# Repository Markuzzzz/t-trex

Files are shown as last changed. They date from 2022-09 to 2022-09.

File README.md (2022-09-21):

# t-trex
Python based quadruped robot powered by Raspberry Pi Zero 2 W



# nifty-inspirations
Nifty Projects - because simple solutions are hard to find!

## Description

t-trex for Raspberry Pi is based on the [Sunfounder Remote Control Crawling Robot](https://www.elektormagazine.com/news/review-sunfounder-remote-control-crawling-quadruped-robot-v2-0) by panerqiang@sunfounder.com, which was the main starting point of the Python code for this project. Especially the calculations related to kinematics of the legs was very helpful. [Regis Hsu](https://www.instructables.com/DIY-Spider-RobotQuad-robot-Quadruped/) on his turn created an amazing 3D printed Quadruped frame which was also based on the Sunfounder project. t-trex is fundamentally built on the work of these two projects to jumpstart and extend with new features. The code written in C was ported to Python and fully refactored, because this programming language is focussed more on the ease of development. So easy to step in for beginners. And when Python is not fast enough (like compiled C code is), it can be combined with the low level C-language. Python is also very popular in the AI community and embedded solutions, resulting in massive amount of libraries to your disposal. Last but not least, Python is also very well supported by the Raspberry Pi ecosystem. 

More to come soon, as I will upload resources to github!

## Features
- Fully Python 3 compatible

- Remote SSH over Wifi support

- PS4 Controller support ([python-evdev](https://python-evdev.readthedocs.io/en/latest/))
    * Crawling Gait Control
    * Speed up/down movements
    * Graceful Quit Program Hard Shutdown (mode 1 soft shutdown)
    * Rumble support
    * System report (mode 1 default stance)

- Different Crwaling Gaits implemented
    * Forward 
    * Backward
    * Left
    * Right
    * Stand (mode 1 head up)
    * Sit (mode 1 head down)
    * Head up/down

- PiJuice Zero Hat
    * Monitoring by PiJuice Zero for save shutdown on low battery voltage
    * custom led usage for simple messages
    * custom switch support for shutting down RPi OS 

- Systemd bootable service (sequence)
    * Logging to System Journal
    * Automatic reconnect at startup
    * Graceful Shutdown sequence on exception

To do
- Interruptable actions
- Advanced movements using analog joysticks
- AI Supervised Neural Net

# Video's of the different build phases
Phase 1: Re-creating Regis Hsu quadruped setup with the Arduino code.

https://user-images.githubusercontent.com/20856694/191291677-cc345581-42a2-487b-9b4e-a81b1ac22a6e.mov

Phase 2: Redesigned model and converted Arduino code to Python
#todo add

## Hardware Configuration
At the heart of this robot runs a RPi Zero W 2 as main cpu. Its controls 12 SG90 micro servo’s distributed over 4 legs using a I2C Servo PWM Pi (made by ABElectronics). To drive the power hungry micro servo’s, the power system consists of two separate power supplies to prevent voltage dips. One dedicated 1S LiPo @ 500 mAh for the RPi, fully managed by a PiJuice module on top of the RPi. Which is also able to charge the LiPo in place by USB or solar power source. The micro servo’s have their own power supply using a 2S LiPo @ 1300 mAh through a 5V buck converter for heavy duty action.

## Components
[Raspberry Pi Zero 2 W](https://www.raspberrypi.com/products/raspberry-pi-zero-2-w/) - the heart of the quadruped robot

[Servo PWM Driver Pi Zero](https://www.abelectronics.co.uk/p/72/servo-pwm-pi-zero) - Servo driver for all 12 servo's

[SG90 Servo](https://www.kiwi-electronics.com/nl/micro-servo-sg90-1-8kg-cm-9g-3018) - Servo type used

[UBEC DC/DC Step-Down Buck Converter - 5V/3A](https://www.kiwi-electronics.com/nl/ubec-dc-dc-step-down-buck-converter-5v-3a-output-9976) - Stepping down 2S 7.8V to 5V converter used for the 12 servo's and servo driver

[Pi-Juice Zero Hat](https://github.com/PiSupply/PiJuice) - Uninterruptable Power Supply (UPS) for the raspberry pi only, to ensure correct execution

[2S LiPo 1300 mAh](https://www.velleman.eu/products/view/?id=434062) - Battery used for servo system with built-in Battery Management System (BMS)

[1S LiPo 500 mAh](https://uk.pi-supply.com/products/lithium-ion-polymer-battery-3-7v-500mah) - Battery used for PiJuice and Raspberry Pi Zero 2 W with BMS

## Body Framework
The body is based on the work of [Regis Hsu](https://www.instructables.com/DIY-Spider-RobotQuad-robot-Quadruped/). To fit my chosen LiPo batteries, I altered his model. This is added to the design models.

## Installation
[Setup Pi Zero 2 W](https://desertbot.io/blog/headless-raspberry-pi-zero-w-2-ssh-wifi-setup-mac-windows-10-steps) - how to setup a headless RPi, this project uses Raspbian OS Lite Legacy 2022-01-28

```bash
# Python3 setup
sudo apt install -y python3-dev
sudo apt install -y python3-smbus i2c-tools
sudo apt install -y python3-pil
sudo apt install -y python3-pip
sudo apt install -y python3-setuptools
sudo apt install -y python3-rpi.gpio

# Evdev 
sudo pip install evdev

# Pijuice Zero
sudo apt-get install pijuice-base

# Servo driver library
git clone https://github.com/abelectronicsuk/ABElectronics_Python_Libraries.git
sudo python3 setup.py install

# PS4 Controller
sudo apt-get install joystick
```

## Additional Commands
```bash
# Increase Swap file 
df -Bm # check free space available
sudo dphys-swapfile swapoff
sudo nano /etc/dphys-swapfile
# Change Swap size
sudo dphys-swapfile setup
sudo dphys-swapfile swapon
sudo reboot now

# Prevent ssh ‘hang’ in terminal
Host ttrex.local
  HostName ttrex.local
  User markus
  ServerAliveInterval 10

# SSH connection set in terminal per server 
Sudo nano ~/.ssh/config
Host keepsdroppingme.com
   ServerAliveInterval 10

For killing it when it gets hang up, you can use the ssh escape character: ~.

# Connect to bluetooth controller
sudo bluetoothctl
agent on
discoverable on
pairable on
default-agent

Scan on
Pair <device id>
Trust <device id>
Connect <device id>

if not connecting, remove first!

# evdev testing
python3 /usr/local/lib/python3.9/dist-packages/evdev/evtest.py
Or
python3 -m evdev.evtest

# i2c commands
# change speed
sudo nano /boot/config.txt
dtparam=i2c_arm=on,i2c_arm_baudrate=200000

# check current clock speed
sudo cat /sys/kernel/debug/clk/clk_summary

# check i2c address layout
i2cdetect -y 1
i2cdetect -y -a 1 # detect outside range
```

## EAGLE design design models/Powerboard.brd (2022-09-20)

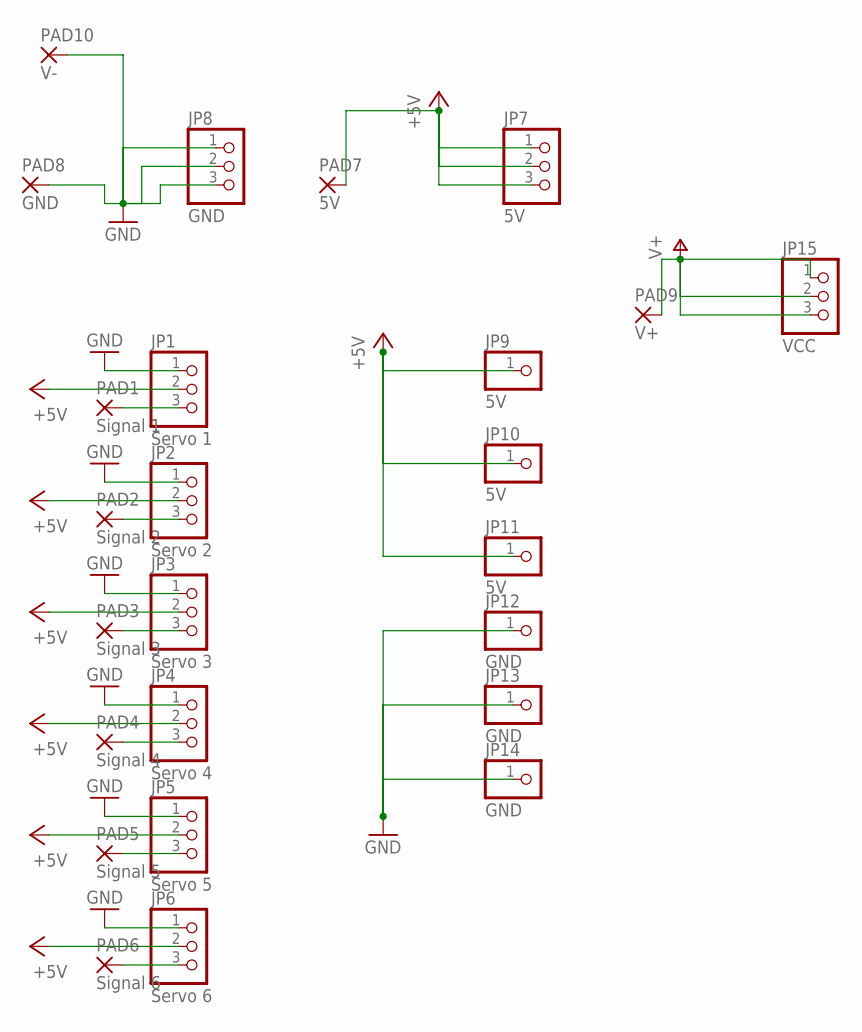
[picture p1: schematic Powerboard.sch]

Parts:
JP1: Servo 1; 1X03
JP2: Servo 2; 1X03
JP3: Servo 3; 1X03
JP4: Servo 4; 1X03
JP5: Servo 5; 1X03
JP6: Servo 6; 1X03
JP7: 5V; 1X03
JP8: GND; 1X03
JP9, JP10, JP11: 5V; 1X01
JP12, JP13, JP14: GND; 1X01
JP15: VCC; 1X03
PAD1: Signal 1; 3,81/1,4
PAD2: Signal 2; 3,81/1,4
PAD3: Signal 3; 3,81/1,4
PAD4: Signal 4; 3,81/1,4
PAD5: Signal 5; 3,81/1,4
PAD6: Signal 6; 3,81/1,4
PAD7: 5V; 3,81/1,4
PAD8: GND; 3,81/1,4
PAD9: V+; 3,81/1,4
PAD10: V-; 3,81/1,4

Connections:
+5V: JP1.2, JP2.2, JP3.2, JP4.2, JP5.2, JP6.2, JP7.1, JP7.2, JP7.3, JP9.1, JP10.1, JP11.1, PAD7.1
GND: JP1.1, JP2.1, JP3.1, JP4.1, JP5.1, JP6.1, JP8.1, JP8.2, JP8.3, JP12.1, JP13.1, JP14.1, PAD8.1, PAD10.1
unnamed: JP1.3, PAD1.1
unnamed: JP2.3, PAD2.1
unnamed: JP3.3, PAD3.1
unnamed: JP4.3, PAD4.1
unnamed: JP5.3, PAD5.1
unnamed: JP6.3, PAD6.1
V+: JP15.1, JP15.2, JP15.3, PAD9.1

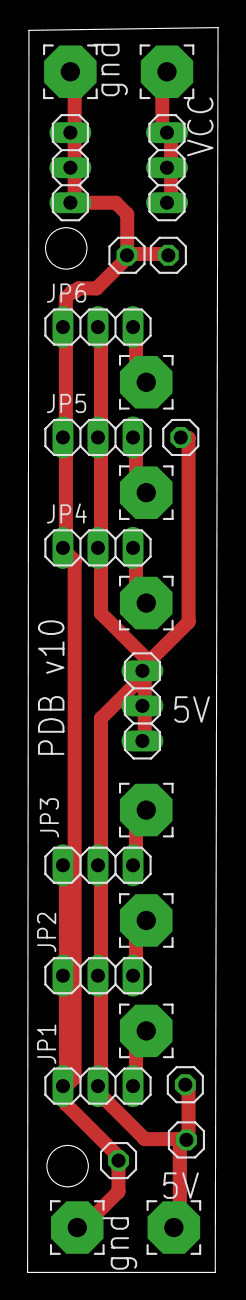
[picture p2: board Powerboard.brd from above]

Board: 2 copper layers, 13.8 x 90.2 mm, 25 parts (0 on the bottom side), 9 nets.

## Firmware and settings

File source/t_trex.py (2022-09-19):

'''
    This module is the main entry point of the program of the t-trex robot.
'''
#!/usr/bin/env python3

# default modules
import sys
import logging
import signal
from exceptions import NoJoystickConnectedException, JoystickDisconnectedException, ProgramKilled, ServoControllerInitializeException
from exceptions import PiJuiceInitializeException
from threading import Thread

# user modules
from quadruped_cpu import QuadrupedCpu
from game_controller import Ps4GameController
from action_controller import ActionController

for handler in logging.root.handlers[:]:
    logging.root.removeHandler(handler)

# Log to console
logging.basicConfig(format='%(asctime)s - %(message)s', level=logging.DEBUG)

# Log to file
#logging.basicConfig(filename='app.log', filemode='a', format='%(name)s - %(levelname)s - %(message)s', level=logging.DEBUG)

# command line arguments
#   usage: python3 t-trex.py STUB
STUB = False
CONTROLLER = True

if len(sys.argv) > 1:
    for argument in sys.argv:
        if argument == "STUB":
            STUB = True
        elif argument == "NO_CONTROLLER":
            CONTROLLER = False

quadruped = QuadrupedCpu()

# Signal Handlers
# Each signal may have a signal handler, which is a function that gets called when the process receives that signal. The function is called in
# "asynchronous mode", meaning that no where in your program you have code that calls this function directly. Instead, when the signal is sent to the process,
# the operating system stops the execution of the process, and "forces" it to call the signal handler function. When that signal handler function returns,
# the process continues execution from wherever it happened to be before the signal was received, as if this interruption never occurred.
def kill_program_handler(signum, frame):
    ''' This handler is called when the kill signal is received'''
    raise ProgramKilled

# When a signal arrives during an I/O operation, it is possible that the I/O operation raises an exception after the signal handler returns.
# This is dependent on the underlying Unix system’s semantics regarding interrupted system calls.
def heart_beat(signum, frame): # pylint: disable=unused-argument
    '''
        This function is the heart beat for updating the I/O service. It may not interrupt other I/O operations. All I/O should be handled from this handler,
        which will be executed in the main thread.
    '''
    #time_started = time.time()
    if quadruped.servo_service(): # timing on RPi Zero W 2: 0.03 seconds @ alarm 0.02 seconds @ 100kHz i2c
        #logging.debug(f"Elapsed: {time.time() - time_started} seconds")
        signal.setitimer(signal.ITIMER_REAL, 0.002) #correct time by substracting the time in this handler from the default alarm time interval. @200 kHz i2c

def shut_down():
    '''
        This function is meant for gracefully shutting down the system.
    '''
    quadruped.release()
    logging.shutdown()    
    sys.exit(0)

def main():
    '''
        Main entry point of the t-trex program.
    '''
    try:
        quadruped.set_status_led(0,255,255)       
        action_controller = ActionController()

        if CONTROLLER:
            controller = Ps4GameController()
            action_controller.register_event_handler(controller.get_last_event)
            event_thread = Thread(target=controller.get_event, name='event_handler', daemon=True)
            event_thread.start()            

        quadruped.initialize(action_controller, controller, STUB)
        quadruped.get_system_report()
        
        signal.signal(signal.SIGTERM, kill_program_handler)
        signal.signal(signal.SIGINT, kill_program_handler)
        signal.signal(signal.SIGALRM, heart_beat)

        signal.setitimer(signal.ITIMER_REAL, 0.02)

        quadruped.set_status_led(0,50,25)

        while True:
            quadruped.run()
    except PiJuiceInitializeException as exception:
        quadruped.set_error_state()
        logging.info(f"Program killed due to initialization exception: running cleanup code...\n Exception Message: {exception}")
    except ProgramKilled as exception:
        quadruped.set_status_led(0,0,0)
        logging.info(f"Program killed due to program killed signal: running cleanup code...")
    except (Exception, JoystickDisconnectedException, NoJoystickConnectedException, ServoControllerInitializeException) as exception:
        quadruped.set_error_state()
        logging.info(f"Program killed due to exception: running cleanup code...\n Exception Message: {exception}")
    finally:
        shut_down()

if __name__ == "__main__":
    main()

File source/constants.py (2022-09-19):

# default settings for speed
MOVE_SPEED = 8
TURN_SPEED = 4
LEG_MOVE_SPEED = 8
BODY_MOVE_SPEED = 3

# If not used set to 0, example: init 90 degrees INIT_LEGS = 90
INIT_LEGS = 0

# Set to 'watch' single leg. Index or 5 if not used
LEG_INDEX = 5

x_offset = 7 
y_start = 0 # NOT USED

length_side = 71
z_ground = - 27

# coxa_len = 27.5 # length_c = 27.5
# femur_len = 70 # length_a = 55 
tibia_len = 80 # length_b = 77.5

coxa_len = 27.5
femur_len = 55
#tibia_len = 77.5

#x_range = (coxa_len + femur_len * 0.70) #66
x_range = 62
z_range = -50

y_step = 45
z_up = -30

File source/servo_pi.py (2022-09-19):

#!/usr/bin/env python
"""
================================================
ABElectronics ServoPi 16-Channel PWM Servo Driver

Requires smbus2 or python smbus to be installed
================================================
"""
# pylint: skip-file
try:
    from smbus2 import SMBus
except ImportError:
    try:
        from smbus import SMBus
    except ImportError:
        raise ImportError("python-smbus or smbus2 not found")
import re
import time
import math
import platform
import RPi.GPIO as GPIO


class PWM(object):
    """
    PWM class for controlling the PCA9685 PWM IC
    """

    # define registers values from datasheet
    __MODE1 = 0x00
    __MODE2 = 0x01
    __SUBADR1 = 0x02
    __SUBADR2 = 0x03
    __SUBADR3 = 0x04
    __ALLCALLADR = 0x05
    __LED0_ON_L = 0x06
    __LED0_ON_H = 0x07
    __LED0_OFF_L = 0x08
    __LED0_OFF_H = 0x09
    __ALL_LED_ON_L = 0xFA
    __ALL_LED_ON_H = 0xFB
    __ALL_LED_OFF_L = 0xFC
    __ALL_LED_OFF_H = 0xFD
    __PRE_SCALE = 0xFE

    # define mode bits
    __MODE1_EXTCLK = 6  # use external clock
    __MODE1_SLEEP = 4  # sleep mode
    __MODE1_ALLCALL = 0  # all call address

    __MODE2_INVRT = 4  # invert output
    __MODE2_OCH = 3  # output type
    __MODE2_OUTDRV = 2  # output type
    __MODE2_OUTNE1 = 0  # output mode when not enabled

    # local variables
    __mode1_default = 0x00
    __mode2_default = 0x0C
    __oe_pin = 7
    __address = 0x40
    __bus = None

    # local methods
    @staticmethod
    def __get_smbus(bus):
        """
        Internal method for getting an instance of the i2c bus

        :param bus: I2C bus number.  If value is None the class will try to
                    find the i2c bus automatically using the device name
        :type bus: int
        :return: i2c bus for target device
        :rtype: SMBus
        :raises IOError: Could not open the i2c bus
        """
        i2c__bus = 1
        if bus is not None:
            i2c__bus = bus
        else:
            # detect the device that is being used
            device = platform.uname()[1]

            if device == "orangepione":  # orange pi one
                i2c__bus = 0

            elif device == "orangepiplus":  # orange pi plus
                i2c__bus = 0

            elif device == "orangepipcplus":  # orange pi pc plus
                i2c__bus = 0

            elif device == "linaro-alip":  # Asus Tinker Board
                i2c__bus = 1

            elif device == "bpi-m2z":  # Banana Pi BPI M2 Zero Ubuntu
                i2c__bus = 0

            elif device == "bpi-iot-ros-ai":  # Banana Pi BPI M2 Zero Raspbian
                i2c__bus = 0

            elif device == "raspberrypi":  # running on raspberry pi
                # detect i2C port number and assign to i2c__bus
                for line in open('/proc/cpuinfo').readlines():
                    model = re.match('(.*?)\\s*:\\s*(.*)', line)
                    if model:
                        (name, value) = (model.group(1), model.group(2))
                        if name == "Revision":
                            if value[-4:] in ('0002', '0003'):
                                i2c__bus = 0  # original model A or B
                            else:
                                i2c__bus = 1  # later models
                            break
        try:
            return SMBus(i2c__bus)
        except IOError:
            raise 'Could not open the i2c bus'

    @staticmethod
    def __checkbit(byte, bit):
        """
        Internal method for reading the value of a single bit within a byte

        :param byte: input value
        :type byte: int
        :param bit: location within value to check
        :type bit: int
        :return: value of selected bit, 0 or 1
        :rtype: int
        """
        value = 0
        if byte & (1 << bit):
            value = 1
        return value

    def __write(self, reg, value):
        """
        Internal method to write data to I2C bus

        :param value: value to write
        :type value: int
        :return: IOError
        :rtype: IOError
        """
        try:
            self.__bus.write_byte_data(self.__address, reg, value)
        except IOError as err:
            return err

    def __read(self, reg):
        """
        Internal method to read data from I2C bus

        :return: IOError
        :rtype: IOError
        """
        try:
            result = self.__bus.read_byte_data(self.__address, reg)
            return result
        except IOError as err:
            return err

    # public methods

    def __init__(self, address=0x40, bus=None):
        """
        init object with i2c address, default is 0x40 for ServoPi board

        :param address: device i2c address, defaults to 0x40
        :type address: int, optional
        :param bus: I2C bus number.  If no value is set the class will try to
                    find the i2c bus automatically using the device name
        :type bus: int, optional
        """
        self.__address = address
        self.__bus = self.__get_smbus(bus)
        self.__write(self.__MODE1, self.__mode1_default)
        self.__write(self.__MODE2, self.__mode2_default)
        GPIO.setwarnings(False)

        mode = GPIO.getmode()  # check if the GPIO mode has been set

        if (mode == 10):  # Mode set to GPIO.BOARD
            self.__oe_pin = 7
        elif (mode == 11):  # Mode set to GPIO.BCM
            self.__oe_pin = 4
        else:  # Mode not set
            GPIO.setmode(GPIO.BOARD)
            self.__oe_pin = 7

        GPIO.setup(self.__oe_pin, GPIO.OUT)

    def set_pwm_freq(self, freq, calibration=0):
        """
        Set the PWM frequency

        :param freq: 40 to 1000
        :type freq: int
        :param calibration: optional integer value to offset oscillator errors.
                            defaults to 0
        :type calibration: int, optional
        :raises ValueError: set_pwm_freq: freq out of range
        """
        if freq < 40 or freq > 1000:
            raise ValueError('set_pwm_freq: freq out of range')

        scaleval = 25000000.0    # 25MHz
        scaleval /= 4096.0       # 12-bit
        scaleval /= float(freq)
        scaleval -= 1.0
        prescale = math.floor(scaleval + 0.5)
        prescale = prescale + calibration
        oldmode = self.__read(self.__MODE1)
        newmode = (oldmode & 0x7F) | 0x10
        self.__write(self.__MODE1, newmode)
        self.__write(self.__PRE_SCALE, int(prescale))
        self.__write(self.__MODE1, oldmode)
        time.sleep(0.005)
        self.__write(self.__MODE1, oldmode | 0x80)

    def set_pwm(self, channel, on_time, off_time):
        """
        Set the output on a single channel
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

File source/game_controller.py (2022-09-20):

'''
    This module implements the EVDEV based game controller.

    The EVDEV package provides bindings to the generic input event interface in Linux. The evdev interface
    serves the purpose of passing events generated in the kernel directly to userspace through character
    devices that are typically located in /dev/input/.

    Documentation: https://python-evdev.readthedocs.io/en/stable/index.html

'''
import logging
import time
from enum import Enum, unique
from evdev import InputDevice, categorize, ecodes, ff # pylint: disable=import-error, unused-import
from exceptions import NoJoystickConnectedException, JoystickDisconnectedException

@unique
class ControllerEvent(Enum):
    '''
        This class defines the unique Controller Events.
    '''
    LEFT_PRESSED = 0
    RIGHT_PRESSED = 1
    UP_PRESSED = 2
    DOWN_PRESSED = 3
    TRIANGLE_PRESSED = 4
    CROSS_PRESSED = 5
    SQUARE_PRESSED = 6
    CIRCLE_PRESSED = 7
    NO_EVENT = 8
    MENU_PRESSED = 9
    R2_PRESSED = 10 # change to R1/L1
    L2_PRESSED = 11    
    RELEASED = 12
    PS_HOME = 13
    PS_SHARE = 14

class Ps4GameController():
    '''
        This class is responsible for the joystick readings and updates for 1 joystick only. This class is easily changed 
        for use with another controller. Just add a new profile instead of read_ps4_profile for the button events.
    '''
    RETRIES = 30

    def __init__(self):
        self._connected = False
        self._event_profile = self.read_ps4_profile
        self._retries = 0
        self._device = None
        self._event = None 
        self._released = False

        self.connect()

    def read_ps4_profile(self, dpad, button_id):
        '''
            This function reads the report for the PS4 Controller Bluetooth

            dpad determines pressed and released button too!
        '''
        #logging.debug(f"dapd {dpad} button id {button_id}")
        self._released = False

        if dpad == (17, -1):
            return ControllerEvent.UP_PRESSED
        elif dpad == (16, 1):
            return ControllerEvent.RIGHT_PRESSED
        elif dpad == (17, 1):
            return ControllerEvent.DOWN_PRESSED
        elif dpad == (16, -1):
            return ControllerEvent.LEFT_PRESSED
        elif dpad == (17, 0):
            return ControllerEvent.RELEASED
        elif dpad == (16, 0):
            return ControllerEvent.RELEASED
        elif dpad == (17, 0):
            return ControllerEvent.RELEASED
        elif dpad == (16, 0):
            return ControllerEvent.RELEASED
        elif button_id == 304 and dpad == (304, 1):
            return ControllerEvent.CROSS_PRESSED
        elif button_id == 304 and dpad == (304, 0):
            return ControllerEvent.RELEASED
        elif button_id == 308 and dpad == (308, 1):
            return ControllerEvent.SQUARE_PRESSED
        elif button_id == 308 and dpad == (308, 0):
            return ControllerEvent.RELEASED
        elif button_id == 307 and dpad == (307, 1):
            return ControllerEvent.TRIANGLE_PRESSED
        elif button_id == 307 and dpad == (307, 0):
            return ControllerEvent.RELEASED
        elif button_id == 305 and dpad == (305, 1):
            return ControllerEvent.CIRCLE_PRESSED
        elif button_id == 305 and dpad == (305, 0):
            return ControllerEvent.RELEASED
        elif button_id == 315 and dpad == (315, 1):
            return ControllerEvent.MENU_PRESSED
        elif button_id == 315 and dpad == (315, 0):
            return ControllerEvent.RELEASED
        elif button_id == 312 and dpad == (312, 1):
            return ControllerEvent.L2_PRESSED    
        elif button_id == 312 and dpad == (312, 0):
            return ControllerEvent.RELEASED            
        elif button_id == 313 and dpad == (313, 1):
            return ControllerEvent.R2_PRESSED
        elif button_id == 313 and dpad == (313, 0):
            return ControllerEvent.RELEASED 
        elif button_id == 314 and dpad == (314, 1):
            return ControllerEvent.PS_SHARE   
        elif button_id == 314 and dpad == (314, 0):
            return ControllerEvent.RELEASED   
        elif button_id == 316 and dpad == (316, 1):
            return ControllerEvent.PS_HOME    
        elif button_id == 316 and dpad == (316, 0):
            return ControllerEvent.RELEASED          
        elif button_id == 6: # todo
            return ControllerEvent.NO_EVENT
        else:
            return ControllerEvent.NO_EVENT

    def connect(self):
        '''
            This function connects the first controller found. It should be a PS4 controller.
        '''
        while(not self._connected and self._retries < Ps4GameController.RETRIES):
            try:
                self._device = InputDevice('/dev/input/event2')
                self._connected = True
                self._retries = 0
                self._device.grab()

                logging.info("Connected PS4 Controller Successfully!")
                logging.info("Use 'Options' to gracefully shutdown the robot!\n")
                logging.info(self._device)
            except OSError as exception:
                self._retries += 1
                logging.info(f"Connecting attempt[{self._retries}] to device failed... retrying in 5 sec!")
                time.sleep(5)

        if not self._connected:
            raise NoJoystickConnectedException("Cannot connect game controller!")

    def rumble(self):
        '''
            This function makes the controller rumble when its has the capability.
        '''
        rumble = ff.Rumble(strong_magnitude=0x0000, weak_magnitude=0xffff)
        ff.EffectType(ff_rumble_effect=rumble)
        duration_ms = 1000

        effect = ff.Effect(
            ecodes.FF_RUMBLE, -1, 0,  # pylint: disable=no-member
            ff.Trigger(0, 0),
            ff.Replay(duration_ms, 0),
            ff.EffectType(ff_rumble_effect=rumble)
        )

        repeat_count = 1
        effect_id = self._device.upload_effect(effect)
        self._device.write(ecodes.EV_FF, effect_id, repeat_count) # pylint: disable=no-member
        time.sleep(1)
        self._device.erase_effect(effect_id)

    def disconnect(self):
        '''
            This function correctly disconnects the controller
        '''
        if self._connected and self._device is not None:
            logging.info("Joystick disconnected")
            self._device.ungrab()
            self._connected = False
            self._device.close()

    def is_connected(self):
        '''
            This function returns the state of the connection.
        '''
        return self._connected

    def get_last_event(self):
        '''
            This function reads event last read from the game controller and resets it. This function is used by other 
            modules to get the last event fired.
        '''
        event = self._event
        self._event = None
        return event
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
